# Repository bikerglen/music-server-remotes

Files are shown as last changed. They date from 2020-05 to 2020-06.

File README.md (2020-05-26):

Mopidy Music Server and Pianobar Player Remote Track/Artist/Album Display

Mopidy Music Server Remote Control

This repository contains the enclsoure designs, circuit board designs, and software for a Mopidy / Pianobar remote track / artist / album display and a Mopidy remote playback control. Both are based on Particle Photons and connect to the Linux server hosting the applications using Wi-Fi. The display uses scrolling 14-segment LED displays for a retro look. The remote control uses custom-labeled NKK pushbutton switches.

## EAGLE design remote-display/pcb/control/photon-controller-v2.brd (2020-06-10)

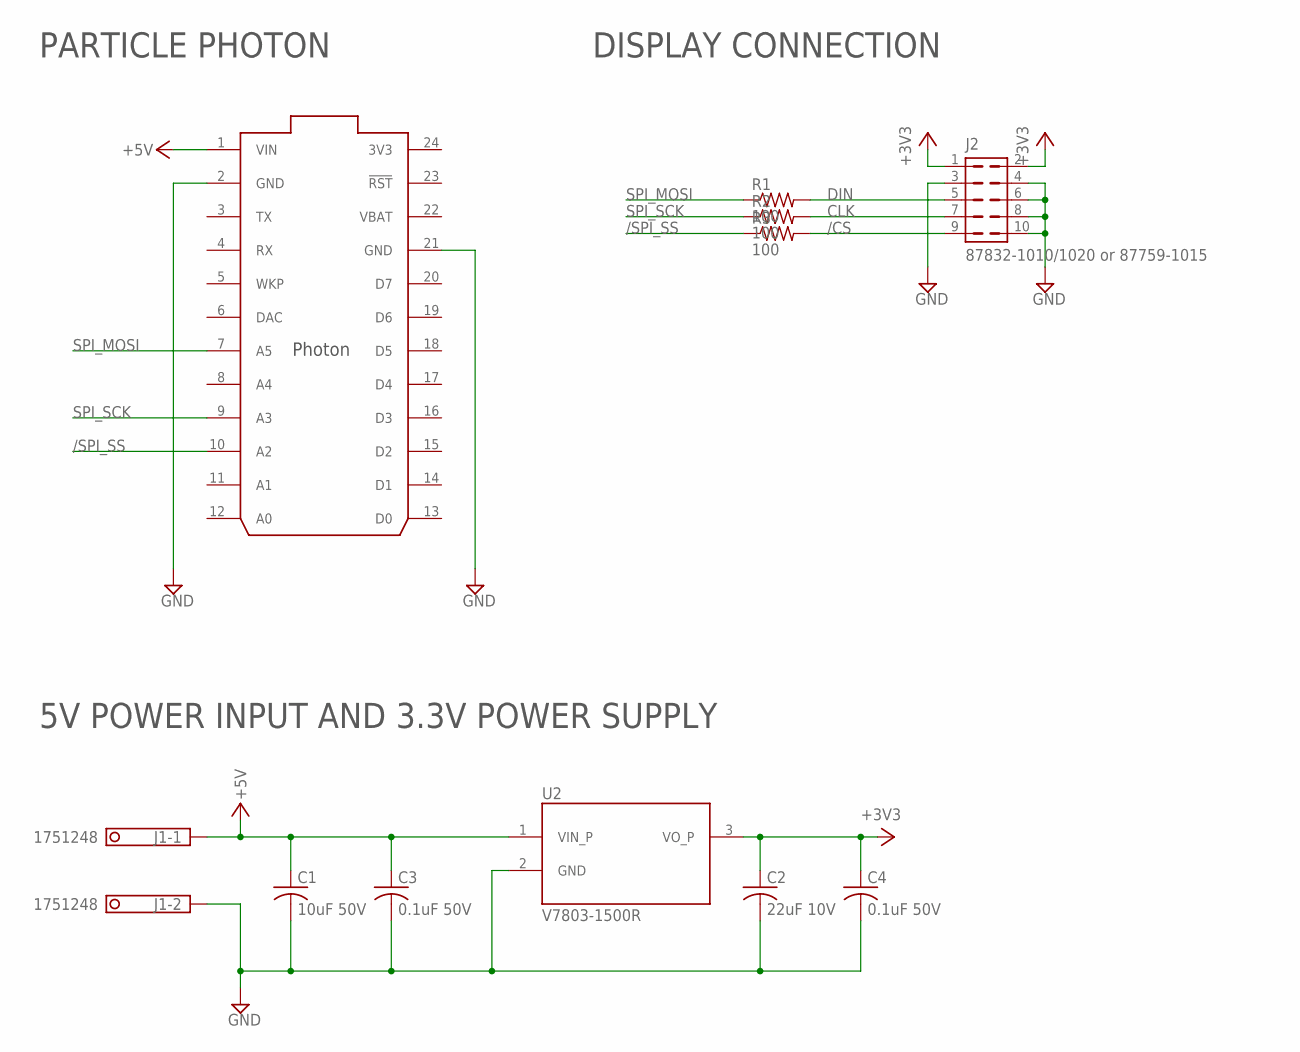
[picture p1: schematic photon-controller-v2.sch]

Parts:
C1: 10uF 50V; C1210K; MFR_PART_NO C1210C106K5RACTU
C2: 22uF 10V; C1206K; MFR_PART_NO C1206C226K8RAC7800
C3, C4: 0.1uF 50V; C1206K; MFR_PART_NO C1206S104M5RACTU
J1: 1751248
J2: 87832-1010/1020 or 87759-1015; 87832-10
R1, R2, R3: 100; R1206
U1: PHOTON_WITH_HEADERS; PHOTON
U2: V7803-1500R; CONV_V7803-1500R

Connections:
3V3: U1.24 (3V3)
+3V3: C2.1, C4.1, J2.1, J2.2, U2.3 (VO_P)
+5V: C1.1, C3.1, J1.1, U1.1 (VIN), U2.1 (VIN_P)
/CS: J2.9, R3.2
/SPI_SS: R3.1, U1.10 (A2)
CLK: J2.7, R2.2
DIN: J2.5, R1.2
GND: C1.2, C2.2, C3.2, C4.2, J1.2, J2.3, J2.4, J2.6, J2.8, J2.10, U1.2 (GND), U1.21 (GND), U2.2 (GND)
SPI_MOSI: R1.1, U1.7 (A5)
SPI_SCK: R2.1, U1.9 (A3)
VBAT: U1.22 (VBAT)

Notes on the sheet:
5V POWER INPUT AND 3.3V POWER SUPPLY
PARTICLE PHOTON
DISPLAY CONNECTION

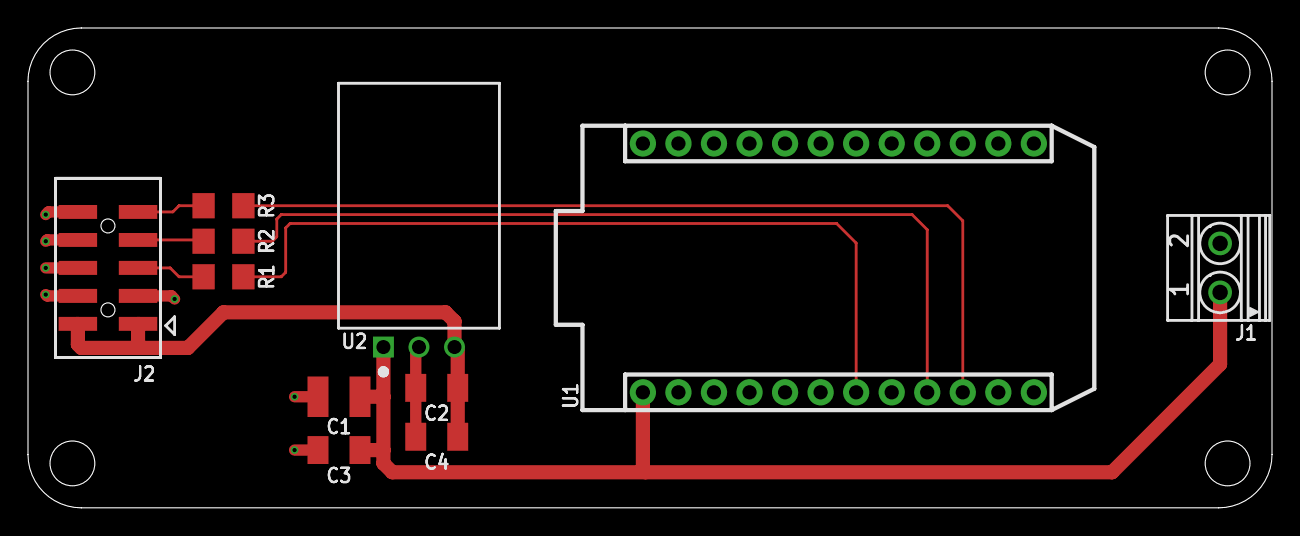
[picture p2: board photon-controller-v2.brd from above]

Board: 2 copper layers, 88.9 x 34.3 mm, 11 parts (0 on the bottom side), 9 nets.

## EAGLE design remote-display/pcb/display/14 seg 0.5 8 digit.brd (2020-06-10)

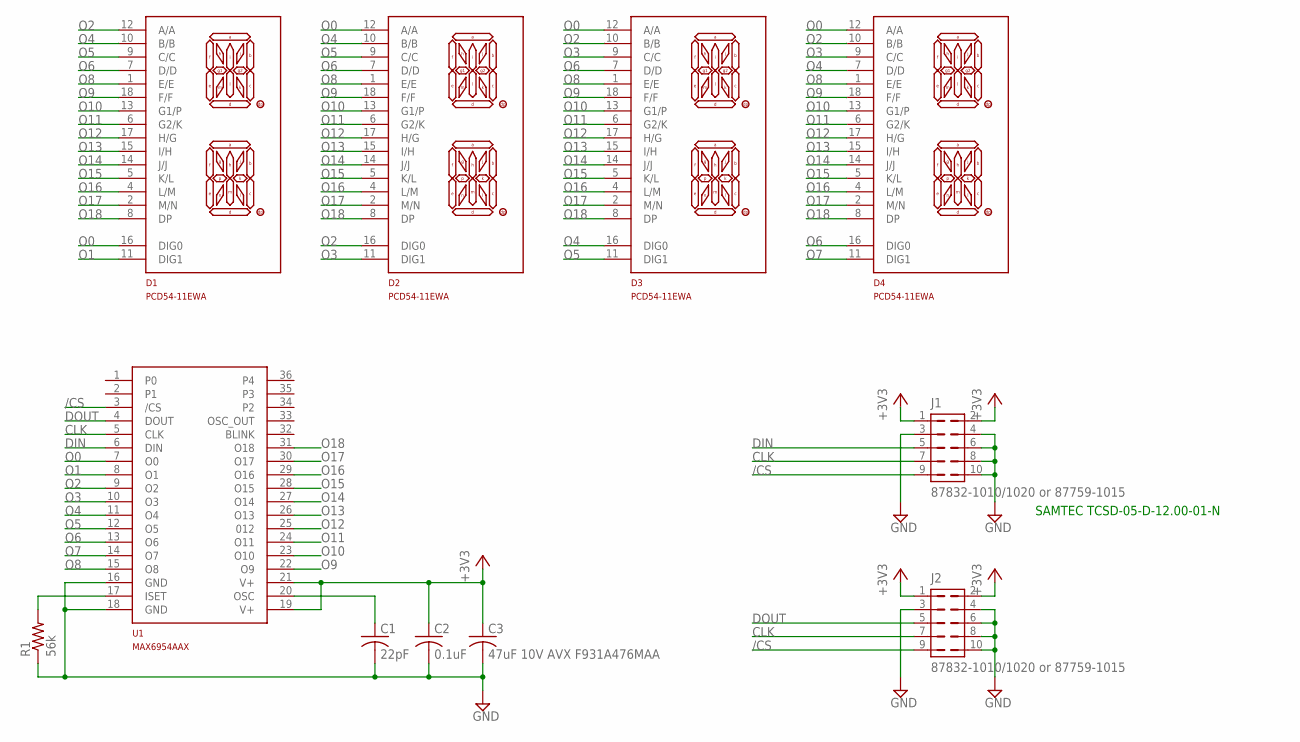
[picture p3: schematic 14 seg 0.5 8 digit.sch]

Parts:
C1: 22pF; C1206
C2: 0.1uF; C1206
C3: 47uF 10V AVX F931A476MAA; C1206
D1, D2, D3, D4: PCD54-11EWA; PDC54-11
J1, J2: 87832-1010/1020 or 87759-1015; 87832-10
R1: 56k; R1206
U1: MAX6954AAX; MAXIM-0.8-SSOP36

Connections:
+3V3: C2.1, C3.1, J1.1, J1.2, J2.1, J2.2, U1.19 (V+), U1.21 (V+)
/CS: J1.9, J2.9, U1.3 (/CS)
CLK: J1.7, J2.7, U1.5 (CLK)
CSET: C1.1, U1.20 (OSC)
DIN: J1.5, U1.6 (DIN)
DOUT: J2.5, U1.4 (DOUT)
GND: C1.2, C2.2, C3.2, J1.3, J1.4, J1.6, J1.8, J1.10, J2.3, J2.4, J2.6, J2.8, J2.10, R1.1, U1.16 (GND), U1.18 (GND)
ISET: R1.2, U1.17 (ISET)
O0: D1.16 (DIG0), D2.12 (A/A), D3.12 (A/A), D4.12 (A/A), U1.7 (O0)
O1: D1.11 (DIG1), U1.8 (O1)
O2: D1.12 (A/A), D2.16 (DIG0), D3.10 (B/B), D4.10 (B/B), U1.9 (O2)
O3: D2.11 (DIG1), D3.9 (C/C), D4.9 (C/C), U1.10 (O3)
O4: D1.10 (B/B), D2.10 (B/B), D3.16 (DIG0), D4.7 (D/D), U1.11 (O4)
O5: D1.9 (C/C), D2.9 (C/C), D3.11 (DIG1), U1.12 (O5)
O6: D1.7 (D/D), D2.7 (D/D), D3.7 (D/D), D4.16 (DIG0), U1.13 (O6)
O7: D4.11 (DIG1), U1.14 (O7)
O8: D1.1 (E/E), D2.1 (E/E), D3.1 (E/E), D4.1 (E/E), U1.15 (O8)
O9: D1.18 (F/F), D2.18 (F/F), D3.18 (F/F), D4.18 (F/F), U1.22 (O9)
O10: D1.13 (G1/P), D2.13 (G1/P), D3.13 (G1/P), D4.13 (G1/P), U1.23 (O10)
O11: D1.6 (G2/K), D2.6 (G2/K), D3.6 (G2/K), D4.6 (G2/K), U1.24 (O11)
O12: D1.17 (H/G), D2.17 (H/G), D3.17 (H/G), D4.17 (H/G), U1.25 (012)
O13: D1.15 (I/H), D2.15 (I/H), D3.15 (I/H), D4.15 (I/H), U1.26 (O13)
O14: D1.14 (J/J), D2.14 (J/J), D3.14 (J/J), D4.14 (J/J), U1.27 (O14)
O15: D1.5 (K/L), D2.5 (K/L), D3.5 (K/L), D4.5 (K/L), U1.28 (O15)
O16: D1.4 (L/M), D2.4 (L/M), D3.4 (L/M), D4.4 (L/M), U1.29 (O16)
O17: D1.2 (M/N), D2.2 (M/N), D3.2 (M/N), D4.2 (M/N), U1.30 (O17)
O18: D1.8 (DP), D2.8 (DP), D3.8 (DP), D4.8 (DP), U1.31 (O18)

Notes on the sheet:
SAMTEC TCSD-05-D-12.00-01-N

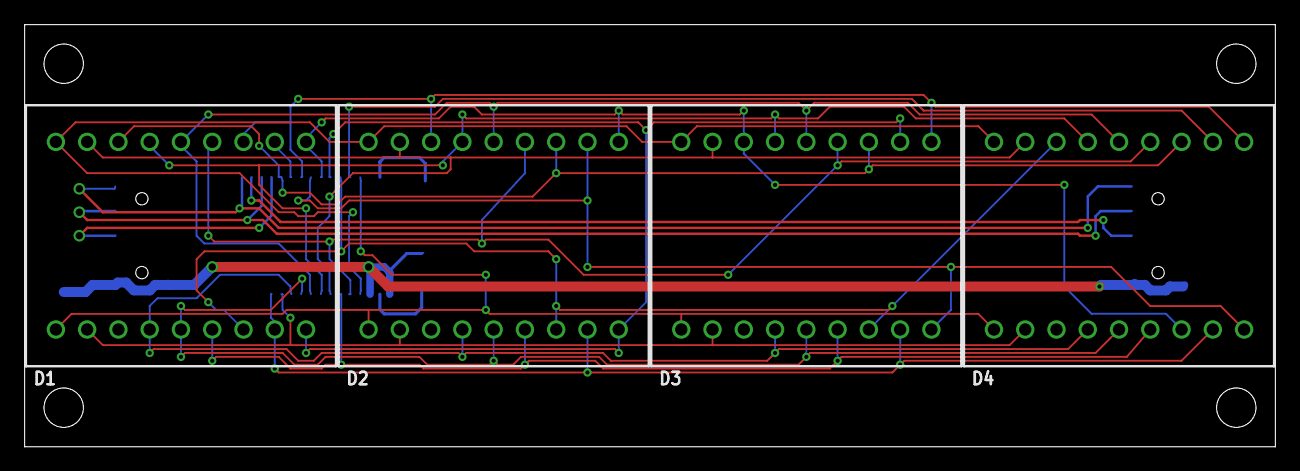
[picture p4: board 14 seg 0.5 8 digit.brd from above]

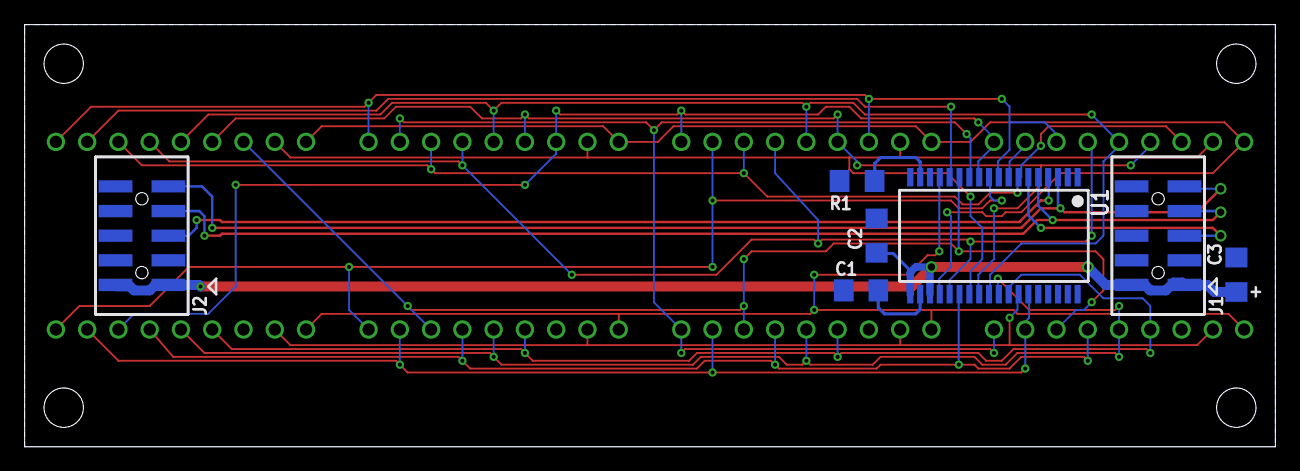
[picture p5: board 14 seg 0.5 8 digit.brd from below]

Board: 2 copper layers, 101.6 x 34.3 mm, 11 parts (7 on the bottom side), 27 nets.

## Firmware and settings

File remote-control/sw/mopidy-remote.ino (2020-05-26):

// This #include statement was automatically added by the Particle IDE.
#include "HttpClient.h"

// This #include statement was automatically added by the Particle IDE.
#include <ArduinoJson.h>

#include "Particle.h"

// system directives
STARTUP(WiFi.selectAntenna(ANT_INTERNAL));
SYSTEM_THREAD(ENABLED);

// Mopidy server IP sddress and port
#define MOPIDY_IP_ADDR 192,168,180,8
#define MOPIDY_PORT    6680

// prototypes
void tick_50Hz (void);
void DebounceButtons (void);

// pushbutton debounce state machine states
#define NUM_BUTTONS 6
int buttons[NUM_BUTTONS] = { A4, A5, A2, A3, A0, A1 };
uint8_t buttonStates[NUM_BUTTONS] = { 0, 0, 0, 0, 0, 0 };
uint8_t buttonTimers[NUM_BUTTONS] = { 0, 0, 0, 0, 0, 0 };
bool buttonDownEvents[NUM_BUTTONS] = { false, false, false, false, false, false };
bool buttonRepeatEnables[NUM_BUTTONS] = { false, false, false, false, true, true };

// LEDs
#define NUM_LEDS 6
int leds[NUM_LEDS] = { D4, D5, D2, D3, D0, D1 };
#define LED_OFF 0
#define LED_ON 1
bool ledStates[NUM_LEDS] = { false, false, false, false, false, false };

// globals
Timer timer (20, tick_50Hz, false);

int timer3s = 0;
int connected = false;
int wiFiReady = false;

void setup()
{
    int i;

    delay (1000);
    Serial.begin (9600);
    Serial.printf ("\n\r\n\rHello, world!\n\r");
    Serial.printlnf("System version: %s", System.version().c_str());

    // init buttons
    for (i = 0; i < NUM_BUTTONS; i++) {
        pinMode (buttons[i], INPUT_PULLUP);
    }
    
    // init LEDs
    for (i = 0; i < NUM_LEDS; i++) {
        pinMode (leds[i], OUTPUT);
        digitalWrite (leds[i], LED_OFF);
    }

    // cycle through the LEDs
    for (i = 0; i < NUM_LEDS+1; i++) {
        digitalWrite (leds[i], LED_ON);
        delay (100);
        digitalWrite (leds[i], LED_OFF);
    }

    // start periodic task to update time displayed on nixie tubes
    timer.start();
}

void loop()
{
    if (!connected && Particle.connected ()) {
        connected = true;
        Serial.printf ("Connected to the Particle Cloud.\n\r");
    } else if (connected && !Particle.connected ()) {
        connected = false;
        Serial.printf ("Disconnected from the Particle Cloud.\n\r");
    }
}

void tick_50Hz (void)
{
    int i;

    timer3s++;
    if (timer3s >= 150) {
        timer3s = 0;
        if (WiFi.ready ()) {
            Serial.printf (".");
        } else if (WiFi.connecting ()) {
            Serial.printf ("C");
        } else if (!WiFi.ready ()) {
            Serial.printf ("X");
        }
    }

    // check WiFi status and re-init udp routines if needed
    if (!wiFiReady && WiFi.ready ()) {
        wiFiReady = true;
        Serial.printf ("Connected to WiFi.\n\r");
    } else if (wiFiReady && !WiFi.ready ()) {
        wiFiReady = false;
        // udp.stop ();
        Serial.printf ("Lost WiFi connection.\n\r");
    }

    // debounce pushbuttons
    DebounceButtons ();

    // process button presses
    for (i = 0; i < NUM_BUTTONS; i++) {
        if (buttonDownEvents[i]) {
            buttonDownEvents[i] = false;
            Serial.printf ("button %d pressed\n\r", i);
            // ledStates[i] = !ledStates[i];
            if (wiFiReady) {
                switch (i) {
                    case 0: PreviousTrack (); break;
                    case 1: NextTrack (); break;
                    case 2: PlayPause (); break;
                    case 3: MuteUnmute (); break;
                    case 4: VolumeDown (); break;
                    case 5: VolumeUp (); break;
                }
            }
        }
    }

    // update leds
    for (i = 0; i < NUM_LEDS; i++) {
        digitalWrite (leds[i], ledStates[i] ? LED_ON : LED_OFF);
        if (wiFiReady) {
            // TODO
        }
    }
}

void DebounceButtons (void)
{
    int i;

    for (i = 0; i < NUM_BUTTONS; i++) {
        switch (buttonStates[i]) {
            case 0:
                buttonStates[i] = (digitalRead (buttons[i]) == 0) ? 1 : 0;
                break;
            case 1:
                if (digitalRead (buttons[i]) == 0) {
                    buttonStates[i] = 2;
                    buttonDownEvents[i] = true;
                    buttonTimers[i] = 0;
                } else {
                    buttonStates[i] = 0;
                }
                break;
            case 2:
                buttonStates[i] = (digitalRead (buttons[i]) == 0) ? 2 : 3;
                buttonTimers[i]++;
                if (buttonTimers[i] == 50) {
                    buttonDownEvents[i] = buttonRepeatEnables[i];
                } else if (buttonTimers[i] == 60) {
                    buttonDownEvents[i] = buttonRepeatEnables[i];
                    buttonTimers[i] = 50;
                }
                break;
            case 3:
                buttonStates[i] = (digitalRead (buttons[i]) == 0) ? 2 : 0;
                break;
            default:
                buttonStates[i] = 0;
                break;
        }
    }
}

HttpClient http;

http_request_t request;
http_response_t response;
http_header_t headers[] = {
    { "Accept", "*/*" },
    { "Content-Type", "application/json" },
    { NULL, NULL }
};


void PreviousTrack (void)
{
    request.ip = IPAddress (MOPIDY_IP_ADDR);
    request.port = MOPIDY_PORT;
    request.path = "/mopidy/rpc";
    request.body = "{\"jsonrpc\": \"2.0\", \"id\": 1, \"method\": \"core.playback.previous\"}";
    http.post (request, response, headers);
    // Serial.println("HTTP Response: ");
    // Serial.println(response.status);
    // Serial.println(response.body);
}

void NextTrack (void)
{
    request.ip = IPAddress (MOPIDY_IP_ADDR);
    request.port = MOPIDY_PORT;
    request.path = "/mopidy/rpc";
    request.body = "{\"jsonrpc\": \"2.0\", \"id\": 1, \"method\": \"core.playback.next\"}";
    http.post (request, response, headers);
    // Serial.println("HTTP Response: ");
    // Serial.println(response.status);
    // Serial.println(response.body);
}

StaticJsonDocument<1024> doc;

void PlayPause (void)
{
    String result;
    
    request.ip = IPAddress (MOPIDY_IP_ADDR);
    request.port = MOPIDY_PORT;
    request.path = "/mopidy/rpc";
    request.body = "{\"jsonrpc\": \"2.0\", \"id\": 1, \"method\": \"core.playback.get_state\"}";
    http.post (request, response, headers);
    // Serial.println ("HTTP Response: ");
    // Serial.println (response.status);
    // Serial.println (response.body);
    if (response.status == 200) {
        deserializeJson (doc, (const char *)response.body.c_str());
        result = doc["result"].as<char*>();
        // Serial.println (result);
        
        if (!strcmp (result.c_str (), "playing")) {
            request.ip = IPAddress (MOPIDY_IP_ADDR);
            request.port = MOPIDY_PORT;
            request.path = "/mopidy/rpc";
            request.body = "{\"jsonrpc\": \"2.0\", \"id\": 1, \"method\": \"core.playback.pause\"}";
            http.post (request, response, headers);
            // Serial.println ("HTTP Response: ");
            // Serial.println (response.status);
            // Serial.println (response.body);
        } else if (!strcmp (result.c_str (), "paused")) {
            request.ip = IPAddress (MOPIDY_IP_ADDR);
            request.port = MOPIDY_PORT;
            request.path = "/mopidy/rpc";
            request.body = "{\"jsonrpc\": \"2.0\", \"id\": 1, \"method\": \"core.playback.resume\"}";
            http.post (request, response, headers);
            // Serial.println ("HTTP Response: ");
            // Serial.println (response.status);
            // Serial.println (response.body);
       }
    }
}

void MuteUnmute (void)
{
    String result;
    
    request.ip = IPAddress (MOPIDY_IP_ADDR);
    request.port = MOPIDY_PORT;
    request.path = "/mopidy/rpc";
    request.body = "{\"jsonrpc\": \"2.0\", \"id\": 1, \"method\": \"core.mixer.get_mute\"}";
    http.post (request, response, headers);
    // Serial.println ("HTTP Response: ");
    // Serial.println (response.status);
    // Serial.println (response.body);
    if (response.status == 200) {
        deserializeJson (doc, (const char *)response.body.c_str());
        int state = doc["result"].as<int>();
        Serial.printf ("state: %d\r\n", state);
        
        if (state == 0) {
            request.ip = IPAddress (MOPIDY_IP_ADDR);
            request.port = MOPIDY_PORT;
            request.path = "/mopidy/rpc";
            request.body = "{\"jsonrpc\": \"2.0\", \"id\": 1, \"method\": \"core.mixer.set_mute\", \"params\": {\"mute\": true}}";
            http.post (request, response, headers);
            // Serial.println ("HTTP Response: ");
            // Serial.println (response.status);
            // Serial.println (response.body);
        } else if (state != 0) {
            request.ip = IPAddress (MOPIDY_IP_ADDR);
            request.port = MOPIDY_PORT;
            request.path = "/mopidy/rpc";
            request.body = "{\"jsonrpc\": \"2.0\", \"id\": 1, \"method\": \"core.mixer.set_mute\", \"params\": {\"mute\": false}}";
            http.post (request, response, headers);
            // Serial.println ("HTTP Response: ");
            // Serial.println (response.status);
            // Serial.println (response.body);
       }
    }
}

void VolumeDown (void)
{
    String result;
    char volumeCommand[128];
    
    request.ip = IPAddress (MOPIDY_IP_ADDR);
    request.port = MOPIDY_PORT;
    request.path = "/mopidy/rpc";
    request.body = "{\"jsonrpc\": \"2.0\", \"id\": 1, \"method\": \"core.mixer.get_volume\"}";
    http.post (request, response, headers);
    // Serial.println ("HTTP Response: ");
    // Serial.println (response.status);
    // Serial.println (response.body);
    if (response.status == 200) {
        deserializeJson (doc, (const char *)response.body.c_str());
        int volume = doc["result"].as<int>();
        Serial.printf ("volume: %d\r\n", volume);
        volume = volume - 10;
        if (volume < 0) {
            volume = 0;
        }
        request.ip = IPAddress (MOPIDY_IP_ADDR);
        request.port = MOPIDY_PORT;
        request.path = "/mopidy/rpc";
        sprintf (volumeCommand, "{\"jsonrpc\": \"2.0\", \"id\": 1, \"method\": \"core.mixer.set_volume\", \"params\": {\"volume\": %d}}", volume);
        request.body = volumeCommand;
        http.post (request, response, headers);
        // Serial.println ("HTTP Response: ");
        // Serial.println (response.status);
        // Serial.println (response.body);
    }
}

void VolumeUp (void)
{
    String result;
    char volumeCommand[128];
    
    request.ip = IPAddress (MOPIDY_IP_ADDR);
    request.port = MOPIDY_PORT;
    request.path = "/mopidy/rpc";
    request.body = "{\"jsonrpc\": \"2.0\", \"id\": 1, \"method\": \"core.mixer.get_volume\"}";
    http.post (request, response, headers);
    // Serial.println ("HTTP Response: ");
    // Serial.println (response.status);
    // Serial.println (response.body);
    if (response.status == 200) {
        deserializeJson (doc, (const char *)response.body.c_str());
        int volume = doc["result"].as<int>();
        Serial.printf ("volume: %d\r\n", volume);
        volume = volume + 10;
        if (volume > 100) {
            volume = 100;
        }
        request.ip = IPAddress (MOPIDY_IP_ADDR);
        request.port = MOPIDY_PORT;
        request.path = "/mopidy/rpc";
        sprintf (volumeCommand, "{\"jsonrpc\": \"2.0\", \"id\": 1, \"method\": \"core.mixer.set_volume\", \"params\": {\"volume\": %d}}", volume);
        request.body = volumeCommand;
        http.post (request, response, headers);
        // Serial.println ("HTTP Response: ");
        // Serial.println (response.status);
        // Serial.println (response.body);
    }
}

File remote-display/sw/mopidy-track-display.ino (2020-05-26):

#include <ArduinoJson.h>
#include "Websockets.h"
#include "Display.h"

STARTUP(WiFi.selectAntenna(ANT_EXTERNAL));
SYSTEM_THREAD(ENABLED);

void tick_50Hz (void);

int connected = false;
Timer timer (20, tick_50Hz, false);

WebSocketClient client;
WebSocketClient client2;

int initState = 0;

void setup ()
{
    int i;
    
    // say hello world
    delay (500);
    Serial.begin (9600);
    Serial.printf ("\n\r\n\rHello, world!\n\r");
    
    // initialize SPI
    SPI.setClockSpeed (1, MHZ);
    SPI.setBitOrder (MSBFIRST);
    SPI.setDataMode (SPI_MODE0);
    SPI.begin (A2);
    digitalWrite (A2, HIGH);

    // init display boards
    disp4xPDC54_Init ();
    
    // display something
    // disp4xPDC54_Display ((const unsigned char *)"* HELLO WORLD *");

    scroll_Message ("CONNECTING");
    
    // start periodic task to update time displayed on nixie tubes
    timer.start();
}

void loop ()
{
    bool result;
    
    if (!connected) {
        if (Particle.connected ()) {
            connected = true;
            scroll_Message ("CONNECTED");
            
            // mopidy client
            client.onMessage (onMessage);
            client.connect ("192.168.180.8", 6680, "", "/mopidy/ws");
            
            // pianobar proxy client
            client2.onMessage (onMessage2);
            client2.connect ("192.168.180.8", 6683, "", "/");
        }
    }
    if (connected) {
        client.monitor ();
        client2.monitor ();
        
        if (initState == 0) {
            result = client.send ("{\"jsonrpc\": \"2.0\", \"id\": 1001, \"method\": \"core.playback.get_current_track\"}");
            if (result) {
                initState = 1;
            }
        } else if (initState == 1) {
            result = client.send ("{\"jsonrpc\": \"2.0\", \"id\": 1002, \"method\": \"core.playback.get_state\"}");
            if (result) {
                initState = 2;
            }
        } else if (initState == 2) {
            result = client.send ("{\"jsonrpc\": \"2.0\", \"id\": 1003, \"method\": \"core.mixer.get_mute\"}");
            if (result) {
                initState = 3;
            }
        } else if (initState == 3) {
            result = client.send ("{\"jsonrpc\": \"2.0\", \"id\": 1004, \"method\": \"core.mixer.get_volume\"}");
            if (result) {
                initState = 4;
            }
        }
    }
}

#define PLAYING 0
#define PAUSED 1
#define STOPPED 2

bool pianoBarMode = false;

int mute = 0;
int volume_timer = 0;
int volume = 0;
int playback = 0;
int pauseTimer = 0;
int scroll_timer = 0;
int scroll_position = 0;
String scroll_string = "";

int pbState = STOPPED;
int pbTimer = 0;

StaticJsonDocument<2048> doc;

void onMessage (WebSocketClient client, char* message)
{
    pianoBarMode = false;
    
    Serial.print ("MPD Received: ");
    Serial.println (message);
    
    deserializeJson (doc, (const char *)message);
    String event = doc["event"].as<char*>();
    int id = doc["id"].as<int>();
    
    Serial.print("Event: ");
    Serial.println (event);
    Serial.print("ID: ");
    Serial.println (id);
    
    if (!strcmp (event, "mute_changed")) {
        mute = doc["mute"].as<int>();
        if (!mute) {
            volume_timer = 50;
        }
        Serial.printf ("Mute: %d\r\n", mute);
    } else if (!strcmp (event, "volume_changed")) {
        volume = doc["volume"].as<int>();
        volume_timer = 50;
        Serial.printf ("Volume: %d\r\n", volume);
    } else if (!strcmp (event, "track_playback_started")) {
        playback = PLAYING;
        String track = doc["tl_track"]["track"]["name"].as<char*>();
        Serial.println (track);
        String artist = doc["tl_track"]["track"]["artists"][0]["name"].as<char*>();
        Serial.println (artist);
        String album = doc["tl_track"]["track"]["album"]["name"].as<char*>();
        Serial.println (album);
        scroll_Message (track + " - " + artist + " - " + album);
    } else if (!strcmp (event, "track_playback_paused")) {
        playback = PAUSED;
        pauseTimer = 5 * 60 * 50;
    } else if (!strcmp (event, "track_playback_resumed")) {
        playback = PLAYING;
    } else if (!strcmp (event, "track_playback_ended")) {
        playback = STOPPED;
        scroll_Message ("                ");
    } else if (!strcmp (event, "playback_state_changed")) {
        String new_state = doc["new_state"].as<char*>();
        if (!strcmp (new_state, "stopped")) {
            playback = STOPPED;
            scroll_Message ("                ");
        }
    } else if (id != 0) {
        if (id == 1001) {
            String result = doc["result"].as<char*>();
            if (!strcmp (result, "null")) {
                scroll_Message ("                ");
            } else {
                String track = doc["result"]["name"].as<char*>();
                Serial.println (track);
                String artist = doc["result"]["artists"][0]["name"].as<char*>();
                Serial.println (artist);
                String album = doc["result"]["album"]["name"].as<char*>();
                Serial.println (album);
                scroll_Message (track + " - " + artist + " - " + album);
            }
        } else if (id == 1002) {
            String result = doc["result"].as<char*>();
            if (!strcmp (result, "playing")) {
                playback = PLAYING;
                Serial.println ("Setting initial playback state to playing.");
            } else if (!strcmp (result, "paused")) {
                playback = PAUSED;
                Serial.println ("Setting initial playback state to paused.");
            } else if (!strcmp (result, "stopped")) {
                playback = STOPPED;
                Serial.println ("Setting initial playback state to stopped.");
                scroll_Message ("                ");
            }
        } else if (id == 1003) {
            mute = doc["result"].as<int>();
            Serial.printf ("Setting initial mute state to %d\n\r", mute);
        } else if (id == 1004) {
            volume = doc["result"].as<int>();
            Serial.printf ("Setting initial volume state to %d\n\r", volume);
        }
    }
}
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

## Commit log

2020-06-10 added board and enclosure files
    [14 seg 0.5 8 digit.brd, 14 seg 0.5 8 digit.sch, photon-controller-v2.brd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]
2020-06-10 moved files around
    [14 seg 0.5 8 digit.brd, 14 seg 0.5 8 digit.sch, photon-controller-v2.brd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]
